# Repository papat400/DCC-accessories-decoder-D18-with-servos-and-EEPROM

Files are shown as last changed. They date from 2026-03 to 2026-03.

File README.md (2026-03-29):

# DCC-accessories-decoder-D18-with-servos-and-EEPROM
ENGLISH :
-------

Based on Ulysse's D18 decoder, allows to use servos direcly from a Nano

Quote from the Ulysse's original project (his file readme.md):

> The D18 is a DIY DCC Accessories decoder based on Arduino board.\
> At the moment, main site and documenation is in French. http://udelmas.e-monsite.com/pages/decodeur-d18.html \
> I created this github to easyly share the Arduino source code (d18_acc_decoder.ino).

Original project is available here : https://github.com/ullysse/d18

My own adaptations are:

1) Using directly some outputs of the arduino to pilot up to 16 servos (max. 12 servos) and/or digital outputs.

2) Keep a backup of the last servos Set Point and digital outputs state in EEPROM memory. This is used to retrieve positions when the arduino is turned off and on again later.
The eeprom is only adapted when a state changes. This allows at least 100,000 changes per servo or binary output, which is more than enough!

If you use and share this project, please mention Ulysse, the creator of this project.

Note : I add an Eagle zip file for the D18 PCB design (made for an arduino NANO).

### Improvements:
2025-03-02: added an output to activate the servo power relay. The sketch only activates this relay when movement is commanded, thus reducing noise.\
2026-03-29: added a feature to allow individual speed control of each servo (V3).

FRANCAIS :
--------

D'après le décodeur d'accessoires D18 d'Ulysse, cette version permet de gérer des servos directement depuis l'arduino.

Citation, d'après le fichier readme.md d'Ulysse :

> Le D18 est un décodeur d'accessoires DCC à faire soi-même avec une carte Arduino.\
> Lien vers le site principal et la documentation: http://udelmas.e-monsite.com/pages/decodeur-d18.html \
> J'ai créé ce github pour facilement partager le code source de l'Arduino (d18_acc_decoder.ino).

Le projet original est disponible ici : https://github.com/ullysse/d18

Mes adaptations sont :

1) Utiliser directement des sorties de l'arduino pour gérer jusqu'à 16 servos (max. 12 servos) et/ou sorties "tout ou rien" (binaires).

2) Effectuer un backup des position "en cours" des servos et des sorties binaires dans l'EEPROM de l'arduino. Ceci permet de récupérer les positions après coupure et réalimentation de l'arduino.
L'EEPROM n'est mise à jour que lors d'un changement d'état de la sortie. Ceci permet au moins 100000 commutations par sortie, ce qui est amplement suffisant !

Si vous utilisez et partagez ce projet, merci de mentionner le créateur initial : Ulysse.

Note : j'ai ajouté un fichier zip Eagle pour le PCB du D18 (pour un arduino NANO).

### Améliorations :
2025-03-02 : utilisation d'une sortie pour activer relais d'alimentation des servos. Le sketch ne commande ce relai que lorsqu'un mouvement est ordonné, cela évite beaucoup de bruit.\
2026-03-29 : ajout d'une fonctionnalité pour pouvoir réguler individuellement la vitesse de chaque servo (V3).

Thierry.

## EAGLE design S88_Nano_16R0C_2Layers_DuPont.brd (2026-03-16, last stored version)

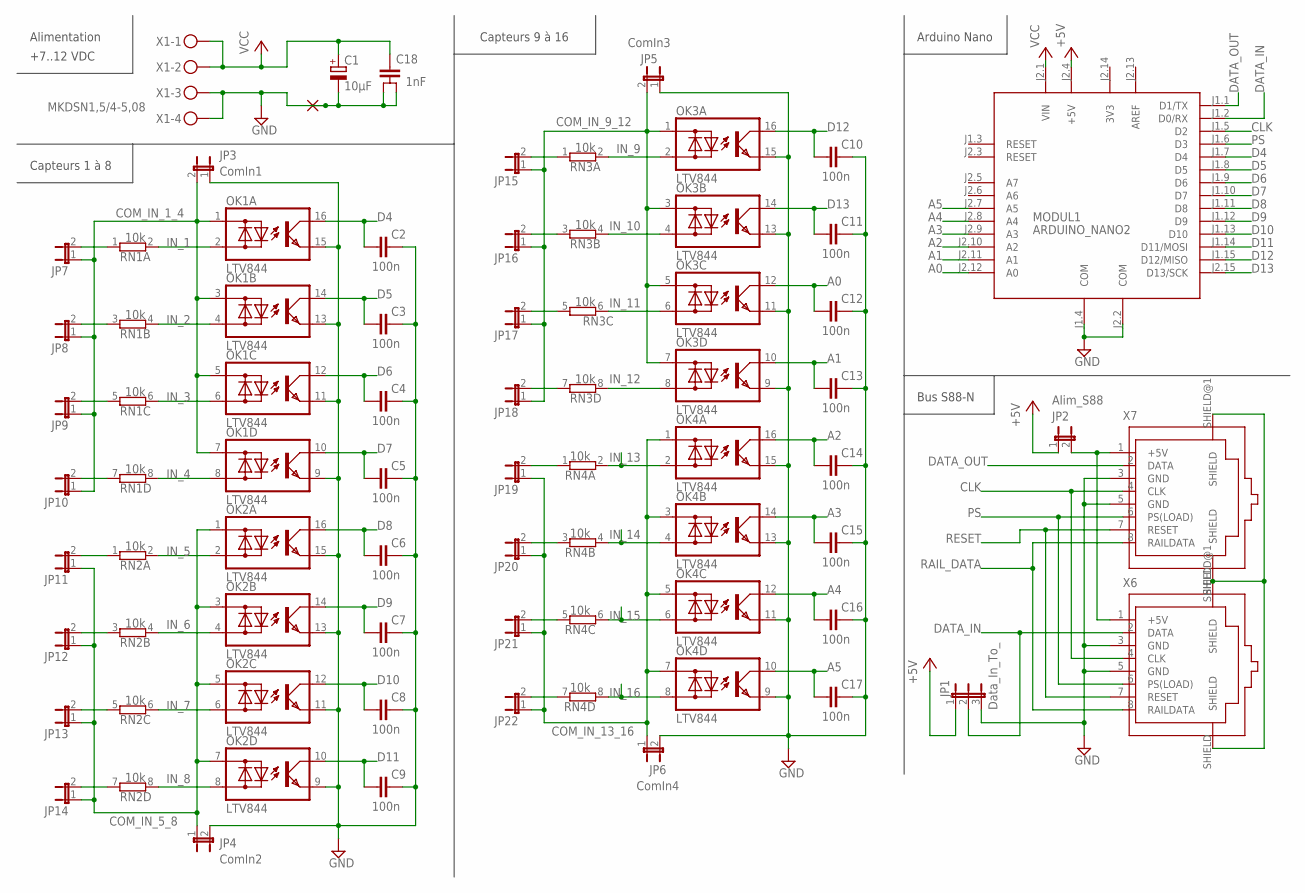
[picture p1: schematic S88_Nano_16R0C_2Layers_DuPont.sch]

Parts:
C1: 10µF; E5-6
C2, C3, C4, C5, C6, C7, C8, C9, C10, C11, C12, C13, C14, C15, C16, C17: 100n; C025-025X050
C18: 1nF; C025_050-024X070
JP1: Data_In_To_; JP2
JP2: Alim_S88; JP1
JP3: ComIn1; JP1
JP4: ComIn2; JP1
JP5: ComIn3; JP1
JP6: ComIn4; JP1
JP7, JP8, JP9, JP10, JP11, JP12, JP13, JP14, JP15, JP16, JP17, JP18, JP19, JP20, JP21, JP22: JP1E; JP1
MODUL1: ARDUINO_NANO2
OK1, OK2, OK3, OK4: LTV844; DIL16
PAD1: 1,9/0,8; 1,6/0,9
RN1, RN2, RN3, RN4: 10k; SIL8
X1: MKDSN1,5/4-5,08
X6, X7: RJ45-SHIELDED

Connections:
3V3: MODUL1.J2.14 (3V3)
+5/S88: JP2.2, X6.1 (+5V), X7.1 (+5V)
+5V: JP1.1, JP2.1, MODUL1.J2.4 (+5V)
A0: C12.1, MODUL1.J2.12 (A0), OK3.12 (C)
A1: C13.1, MODUL1.J2.11 (A1), OK3.10 (C)
A2: C14.1, MODUL1.J2.10 (A2), OK4.16 (C)
A3: C15.1, MODUL1.J2.9 (A3), OK4.14 (C)
A4: C16.1, MODUL1.J2.8 (A4), OK4.12 (C)
A5: C17.1, MODUL1.J2.7 (A5), OK4.10 (C)
AREF: MODUL1.J2.13 (AREF)
CLK: MODUL1.J1.5 (D2), X6.4 (CLK), X7.4 (CLK)
COM_IN_1_4: JP3.2, JP7.1, JP8.1, JP9.1, JP10.1, OK1.1 (AC1), OK1.3 (AC1), OK1.5 (AC1), OK1.7 (AC1)
COM_IN_5_8: JP4.1, JP11.1, JP12.1, JP13.1, JP14.1, OK2.1 (AC1), OK2.3 (AC1), OK2.5 (AC1), OK2.7 (AC1)
COM_IN_9_12: JP5.2, JP15.1, JP16.1, JP17.1, JP18.1, OK3.1 (AC1), OK3.3 (AC1), OK3.5 (AC1), OK3.7 (AC1)
COM_IN_13_16: JP6.1, JP19.1, JP20.1, JP21.1, JP22.1, OK4.1 (AC1), OK4.3 (AC1), OK4.5 (AC1), OK4.7 (AC1)
D4: C2.1, MODUL1.J1.7 (D4), OK1.16 (C)
D5: C3.1, MODUL1.J1.8 (D5), OK1.14 (C)
D6: C4.1, MODUL1.J1.9 (D6), OK1.12 (C)
D7: C5.1, MODUL1.J1.10 (D7), OK1.10 (C)
D8: C6.1, MODUL1.J1.11 (D8), OK2.16 (C)
D9: C7.1, MODUL1.J1.12 (D9), OK2.14 (C)
D10: C8.1, MODUL1.J1.13 (D10), OK2.12 (C)
D11: C9.1, MODUL1.J1.14 (D11/MOSI), OK2.10 (C)
D12: C10.1, MODUL1.J1.15 (D12/MISO), OK3.16 (C)
D13: C11.1, MODUL1.J2.15 (D13/SCK), OK3.14 (C)
DATA_IN: JP1.2, MODUL1.J1.2 (D0/RX), X6.2 (DATA)
DATA_OUT: MODUL1.J1.1 (D1/TX), X7.2 (DATA)
GND: C1.-, C2.2, C3.2, C4.2, C5.2, C6.2, C7.2, C8.2, C9.2, C10.2, C11.2, C12.2, C13.2, C14.2, C15.2, C16.2, C17.2, C18.2, C18.3, JP1.3, JP3.1, JP4.2, JP5.1, JP6.2, MODUL1.J1.4 (COM), MODUL1.J2.2 (COM), OK1.9 (E), OK1.11 (E), OK1.13 (E), OK1.15 (E), OK2.9 (E), OK2.11 (E), OK2.13 (E), OK2.15 (E), OK3.9 (E), OK3.11 (E), OK3.13 (E), OK3.15 (E), OK4.9 (E), OK4.11 (E), OK4.13 (E), OK4.15 (E), PAD1.1, X1.3, X1.4, X6.3 (GND), X6.5 (GND), X7.3 (GND), X7.5 (GND)
IN_1: OK1.2 (AC2), RN1.2
IN_2: OK1.4 (AC2), RN1.4 (2)
IN_3: OK1.6 (AC2), RN1.6 (2)
IN_4: OK1.8 (AC2), RN1.8 (2)
IN_5: OK2.2 (AC2), RN2.2
IN_6: OK2.4 (AC2), RN2.4 (2)
IN_7: OK2.6 (AC2), RN2.6 (2)
IN_8: OK2.8 (AC2), RN2.8 (2)
IN_9: OK3.2 (AC2), RN3.2
IN_10: OK3.4 (AC2), RN3.4 (2)
IN_11: OK3.6 (AC2), RN3.6 (2)
IN_12: OK3.8 (AC2), RN3.8 (2)
IN_13: OK4.2 (AC2), RN4.2
IN_14: OK4.4 (AC2), RN4.4 (2)
IN_15: OK4.6 (AC2), RN4.6 (2)
IN_16: OK4.8 (AC2), RN4.8 (2)
unnamed: JP7.2, RN1.1
unnamed: JP8.2, RN1.3 (1)
unnamed: JP9.2, RN1.5 (1)
unnamed: JP10.2, RN1.7 (1)
unnamed: JP11.2, RN2.1
unnamed: JP19.2, RN4.1
unnamed: JP14.2, RN2.7 (1)
unnamed: JP13.2, RN2.5 (1)
unnamed: JP18.2, RN3.7 (1)
unnamed: JP20.2, RN4.3 (1)
unnamed: JP12.2, RN2.3 (1)
unnamed: JP21.2, RN4.5 (1)
unnamed: JP22.2, RN4.7 (1)
unnamed: JP15.2, RN3.1
unnamed: JP16.2, RN3.3 (1)
unnamed: JP17.2, RN3.5 (1)
PS: MODUL1.J1.6 (D3), X6.6 (PS(LOAD)), X7.6 (PS(LOAD))
RAIL_DATA: X6.8 (RAILDATA), X7.8 (RAILDATA)
RESET: X6.7 (RESET), X7.7 (RESET)
SHIELD: X6.SHIELD, X6.SHIELD@1 (SHIELD), X7.SHIELD, X7.SHIELD@1 (SHIELD)
VCC: C1.+, C18.1, MODUL1.J2.1 (VIN), X1.1, X1.2

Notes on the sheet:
Alimentation
Capteurs 9 à 16
Capteurs 1 à 8
Arduino Nano
Bus S88-N
+7..12 VDC

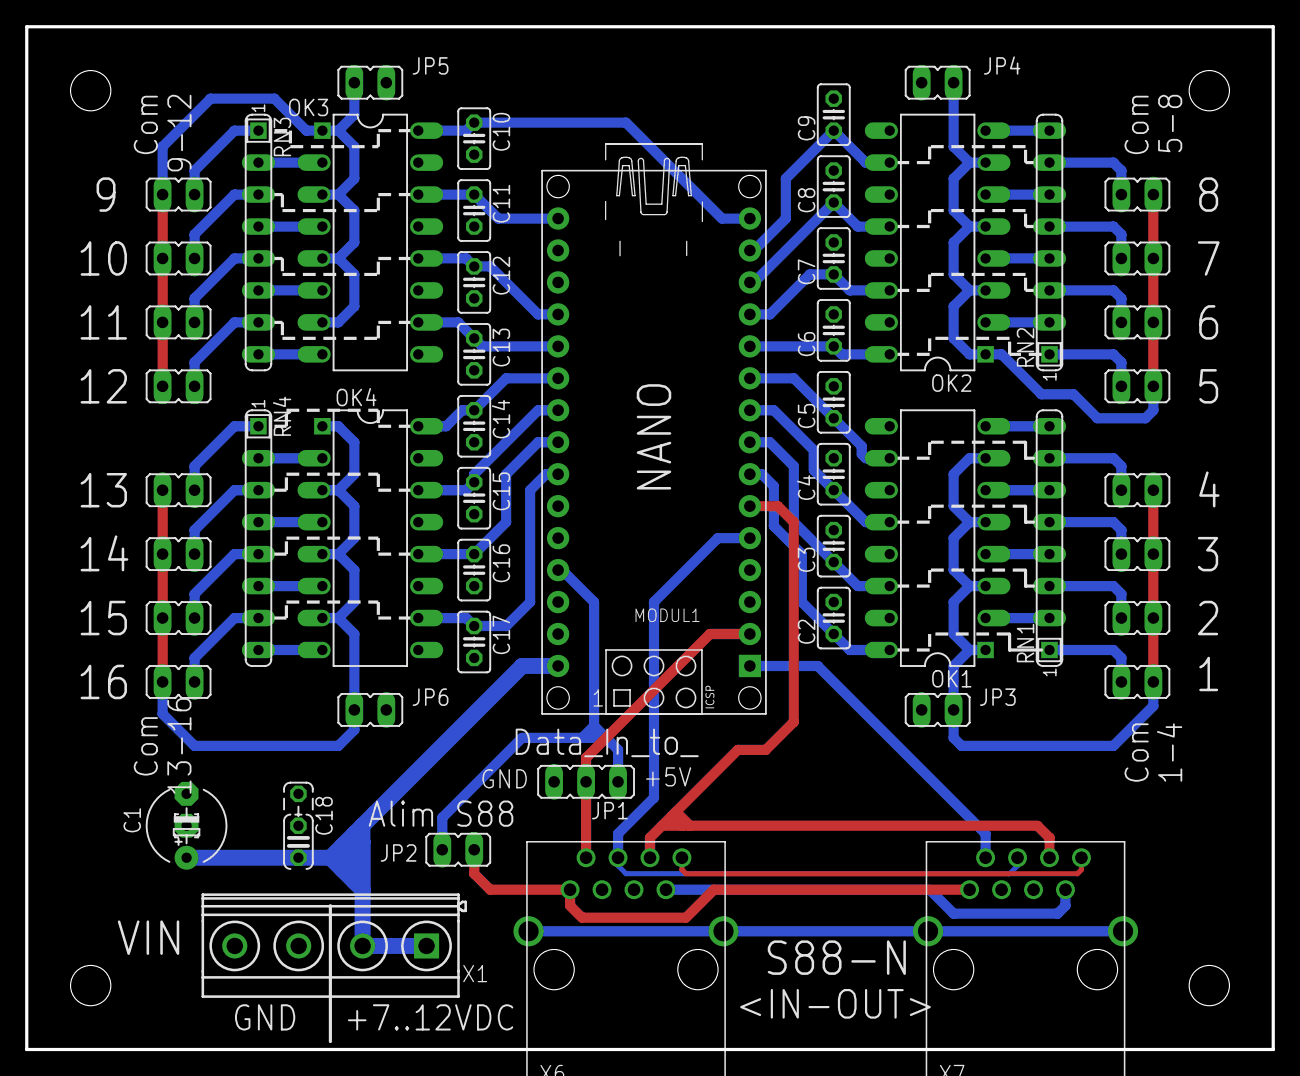
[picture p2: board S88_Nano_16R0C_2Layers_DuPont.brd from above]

Board: 2 copper layers, 99.1 x 81.3 mm, 53 parts (0 on the bottom side), 63 nets.

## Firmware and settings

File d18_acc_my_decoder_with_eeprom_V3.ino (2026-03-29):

/* D18 ACC DECODER

  Introduction:
  ENGLISH:

    Without extension, this decoder allows to control 16 direct outputs (or 8 output pairs).
        This is the double of traditional DCC accessories decoders having 4 output pairs.
        Output can be fix or generate pulses (20ms->65s with 20ms resolution).
        Configuration is done in this code (in USER part) instead of using CVs.
    You can add MAX7219/21 modules in place of 3 direct outputs. Each module can drive 64 LEDs.
        Actual SW supports 4 modules so 256 leds.
        You can also control LEDs blinking and blinking phase.
    You can add PCA9685 modules in place of 2 direct outputs. Each module adds 16 outputs.
        Each of these outputs can work in PWM mode (0-100%), this allow dimming to control for instance lights intensity or motor speed.
            To have the behavior of a traditional output, you can une 0% and 100%.
        Each of these outputs can also work in SERVO mode to control a servo-motor.
        Actual SW supports 6 modules so 96 new outputs.
    You can also drive Neopixels (chained RGB leds) in place of 1 direct out.
    To be compatible with any centrals (and mainly your central) and be versatile,
        User can map any order ("Accessory" or "Output") from DCC signal to any output.
    By default SW is delivered to manage 8 pairs on address 10 & 11

  FRANCAIS:

   Sans extension, ce décodeur permet de contrôler 16 sorties directes (ou 8 paires de sorties).
       Cela est le double d'un décodeur d'accessoires traditionnel (4 paires de sorties).
       Les sorties peuvent être fixes ou générer des impulsions (20ms->65s avec une résolution de 20ms).
   Vous pouvez ajouter des modules MAX7219/21 à la place de 3 sorties directes. Chaque module supporte 64 LEDs.
       Le programme actuel supporte 4 modules, soit 256 LEDs.
       Vous pouvez aussi contrôler le clignotement des LEDs ainsi que la phase.
   Vous pouvez ajouter des modules PCA9685 à la place de 2 sorties directes. Chaque module ajoute 16 sorties.
       Chacune de ces sorties peut fonctionner en mode PWM (0-100%), cela permet de faire varier l'éclairage ou la vitesse d'un moteur.
           Pour une sortie traditionnelle, utilisez 0% ou 100%
       Chacune de ces sorties peut fonctioner en mode SERVO (500ms->2500ms 50Hz), pour contrôler un servo-moteur.
       Le programme actuel supporte 6 modules, soit 96 nouvelles sorties.
   Vous pouvez aussi contrôler des Néopixels (LEDs chainables multicolores) à la place d'une sortie directe.
   Pour être compatible avec toutes les centrales (et surtout la vôtre) et être passe partout.
       L’utilisateur peut utiliser n'importe quel ordre DCC ("Accessory" ou "Output") pour contrôler n'importe quelle sortie.
       La configuration se fait dans ce code (dans la partie USER) au lieu d'utiliser les CV.
       Par défaut le programme est configuré pour contrôler 8 paires d sorties.

  History:
    2017-02-08: Ulysse Delmas-Begue: ajout de la rotation lente des servos
                                     changement de la resolution des tempos de 20ms a 125ms
    2017-01-12: Ulysse Delmas-Begue: support Arduino Mega board to add 50 direct outputs in addition to Arduino UNO and Nano
                                     AT Mega is enbaled when user select Arduino Mega board in Arduino IDE
                                     serigraphied number is now used for direct outputs instead of out 0-15
                                     output number is checked in user_out function
    2017-01-12: Ulysse Delmas-Begue: support 256LEDs (via 4 MAX7219/21) and 96PWM/SERCO (via 6 PCA9685)
    2017-01-11: Ulysse Delmas-Begue: add 128leds (via MAX7219/21) OK, 48pwm/servos (via PCA9685 I2C), 60neopixels  (test MAX, PCA(PWM&SRV) et pulses ok, neo not stable board finish to freeze)
    2017-01-10: Ulysse Delmas-Begue: creation (et test out ok avec D17)
    2026-03-29: Thierry:  added a feature to allow individual speed control of each servo.
                          ajout d'une fonctionnalité pour pouvoir réguler individuellement la vitesse de chaque servo.

  To be done:
    None

  License: GPL v2

  Notes:
    - I used foloowing code as startup point:
        Simple DCC Led Accessory Decoder Luca Dentella, 25.11.2017
        http://www.lucadentella.it/en/2017/11/25/dcc-decoder-accessori-per-led/
    - This code needs the following library to be installed in the Arduino IDE
        https://github.com/mrrwa/NmraDcc
    - switching on an output of the pair, automaticaaly switch off the other output
    - onboard led blinks at 1Hz or 4 Hz during 1sec when a packet matches

    Normally decoder address and pulses are set by following CVs but here they are hardcoded
    - CV513 ADR LSB 6bits
    - CV515 pair 0 pulse
    - CV516 pair 1 pulse
    - CV517 pair 2 pulse
    - CV518 pair 3 pulse duration
    - CV521 ADR MSB 3bits

  Pinout on an Arduino UNO

     CLI +++ +++ +++ +++ +++    +++ +++ +++ +++ +++ DCC  TX  RX
     D13 D12 D11 D10  D9  D8     D7  D6  D5  D4  D3  D2  D1  D0
    ###########################################################      +++ = out
    #USB###########################################TOP#view####      +-+ = out or used by MAX,PCA,NEO
    ###########################################################      use following numbers in SW: 3-12 & A0-A5
    ###########################################################      max out = 16
     x   x   x   x   x   x   x   x      A0  A1  A2  A3  A4  A5
                                   +-+ +-+ +-+ +-+ +-+ +-+
                                   CLK DAT LLED NEO SDA SCK

  Pinout on an Arduino Nano

     +++ +++ +++ +++ +++  +++ +++ +++ +++ +++ DCC          TX  RX
     D12 D11 D10  D9  D8  D7  D6  D5  D4  D3  D2 GND  RST  D1  D0    +++ = out
    ##############################################################   +-+ = out when not used by MAX,PCA,NEO
    USB ##############################################TOP#view####   use following numbers in SW: 3-12 & A0-A5
    ##############################################################   max out = 16
     D13 3.3   X  A0  A1  A2  A3  A4  A5  A6  A7  5V  RST GND VIN
     CLI          +-+ +-+ +-+ +-+ +-+ +-+
                  CLK DAT LLED NEO SDA SCK

  Pinout on Arduino Mega

  horizontal connectors

     CLI +++ +++ +++ +++ +++    +++ +++ +++ +++ +++ DCC  TX  RX    +++ +++ +++ +++ +++ +++ +++ +++
     D13 D12 D11 D10  D9  D8     D7  D6  D5  D4  D3  D2  D1  D0    D14 D15 D16 D17 D18 D19 D20 D21
    #######################################################################################################
    USB############################################TOP#view################################################
    #######################################################################################################
    #######################################################################################################
     x   x   x   x   x   x   x   x      A0  A1  A2  A3  A4  A5  A6 A7     A8  A9 A10 A11 A12 A13 A14 A15
                                       +-+ +-+ +-+ +-+ +-+ +-+ +++ +++   +++ +++ +++ +++ +++ +++ +++ +++
                                       CLK DAT LLED NEO SDA SCK

  vertical connector:

         GND ##### GND
     +++ D22 ##### D23 +++      +++ = out
     +++ D24 ##### D25 +++      out when not used by MAX,PCA,NEO
     +++ D26 ##### D27 +++      use following numbers in SW: 3-12,14-53 & A0-A15
     +++ D28 ##### D29 +++      max out = 66
     +++ D30 ##### D31 +++
     +++ D32 ##### D33 +++
     +++ D34 ##### D35 +++
     +++ D36 ##### D37 +++
     +++ D38 ##### D39 +++
     +++ D40 ##### D41 +++
     +++ D42 ##### D43 +++
     +++ D44 ##### D45 +++
     +++ D46 ##### D47 +++
     +++ D48 ##### D49 +++
     +++ D50 ##### D51 +++
     +++ D52 ##### D53 +++
         GND ##### GND
*/
//==============================================================================================
/*

  English :
  ---------
  Adaptations made to use servos directly on arduino pins.
  Author : Thierry.

  The main changes are made in 5 "blocks" of code, named : part 1, 2, 3, 4 and 5.
  part 1 is in "declaration" section;
  part 2 in the user_init() function;
  part 3 in the user_notify_bas_acc_dec();
  part 4 containing the functions created for this modification;
  part 5 in the loop().

  Some additional lines are spotted by the comment !-Thierry-!
  ++++++++++++++++++++++++++++++++++++++++++++++++++++++++++++++++++++++++++++++++++

  Notes about DCC decoding related to the intended use :
  ------------------------------------------------------

  Used command station : Yaassan's Desktop Station (hereinafter named DS) - for details, see https://desktopstation.net/
  DS sends accessory orders in DCC and / or MM2 (configurable choice).
  D18 decoder don't manage MM2, all that follows only relates to the decoding of DCC accessories.

  Used DCC mode by DS : "Basic Accessory Decoder"
  DS can manage 2044 accessories addresses, ie 4 accessories for each of the 511 basic DCC addresses.

  About turnouts:

  One DS address "uses" two consecutive bits in one DCC address.
    Example:
      DS address  -   DS functionality (examples)   -   DCC address
      ----------      ---------------------------       -----------
           1       -  turnout in deviated position  -  1 / bit 0 (pulse)
           1       -  turnout in right position     -  1 / bit 1 (pulse)
           2       -  two-color signal RED          -  1 / bit 2
           2       -  two-color signal GREEN        -  1 / bit 3
           3       -  turnout in deviated position  -  1 / bit 4 (pulse)
           3       -  turnout in right position     -  1 / bit 5 (pulse)
           4       -  two-color signal RED          -  1 / bit 5
           4       -  two-color signal GREEN        -  1 / bit 7

    For each of its turnout's addresses, DS sends a pulse to the "ONE" state for a few tenths of seconds and then resets the output to "ZERO".
      This indicates that the "standard" of DS operation clearly relates to the use of solenoid-controlled turnouts.
    Each command is repeated four times.
      Example:
      Turnout command on address DS 1: switching on "straight"
        #3 129 249 120 BAS ACC pkt adr(1-511)=1 out(0-7)=1 val(0-1)=1 => command DCC address n°1 / bit 1 to the state ONE ; repeated four times
        #3 129 249 120 BAS ACC pkt adr(1-511)=1 out(0-7)=1 val(0-1)=1
        #3 129 249 120 BAS ACC pkt adr(1-511)=1 out(0-7)=1 val(0-1)=1
        #3 129 249 120 BAS ACC pkt adr(1-511)=1 out(0-7)=1 val(0-1)=1
        ... a few tenths of a second ...
        #3 129 241 112 BAS ACC pkt adr(1-511)=1 out(0-7)=1 val(0-1)=0 => command DCC address n°1 / bit 1 to the state ZERO ; repeated four times
        #3 129 241 112 BAS ACC pkt adr(1-511)=1 out(0-7)=1 val(0-1)=0
        #3 129 241 112 BAS ACC pkt adr(1-511)=1 out(0-7)=1 val(0-1)=0
        #3 129 241 112 BAS ACC pkt adr(1-511)=1 out(0-7)=1 val(0-1)=0

      Switching on "deviated turnout" will use the same scheme on DCC address 1 / bit 0

    Improvement :
    -------------
      Added an option to use a servo power relay.

      Cause: on power-ON, there is still no PWM signal to the servos. If they are already supplied with + 5V, they will then quickly move 
        to a random position and certainly exceed the programmed stops, which could be bad for the driven mechanics.
      Solution: add a relay to supply power to the servos only when the PWM signal is present.
      Disadvantage: this uses one of the available outputs.


  Français :
  ----------
  Adaptations apportées pour gérer des servos directement depuis les pins Arduino
  Auteur : Thierry.

  Modifications principales effectuées en 5 "blocs" de code, nommés : partie 1, 2, 3, 4 et 5.
  partie 1 dans les déclarations ;
  partie 2 dans la fonction user_init() ;
  partie 3 dans la fonction user_notify_bas_acc_dec() ;
  partie 4 contenant les fonctions créées pour cette modification, ;
  partie 5 dans la fonction loop()
  
  Quelques lignes supplémentaires sont repérables par le commentaire !-Thierry-! .
  ++++++++++++++++++++++++++++++++++++++++++++++++++++++++++++++++++++++++++++++++

  Notes sur le décodage DCC lié à l'utilisation envisagée :
  ---------------------------------------------------------
  Station de commande utilisée : Desktop Station (ci-après nommé DS) de Yaasan - voir https://desktopstation.net/
  DS gère les commandes d'accessoires en DCC et / ou en MM2 (choix paramétrable).
  Le MM2 n'est pas traité par le décodeur D18, tout ce qui suit ne concerne que le décodage d'accessoires DCC.

  Mode utilisé par DS en DCC : "Basic Accessory Decoder"
  DS peut piloter 2044 adresses d'accessoires, càd 4 accessoires pour chacune des 511 adresses basiques DCC.

  Concernant les aiguilles :

    Une adresse DS "consomme" deux bits consécutifs dans l'adresse DCC.
      Exemple :
      adresse DS   -      fonctionnalité DS         -   adresse DCC
      ----------          -----------------             -----------
           1       -  aiguille en position déviée   -  1 / bit 0 (impulsion)
           1       -  aiguille en position droite   -  1 / bit 1 (impulsion)
           2       -  signal bicolore ROUGE         -  1 / bit 2
           2       -  signal bicolore VERT          -  1 / bit 3
           3       -  aiguille en position déviée   -  1 / bit 4 (impulsion)
           3       -  aiguille en position droite   -  1 / bit 5 (impulsion)
           4       -  signal bicolore ROUGE         -  1 / bit 5
           4       -  signal bicolore VERT          -  1 / bit 7

    Pour chacune de ses adresses concernant une aiguille, DS envoie une impulsion à l'état UN durant quelques dixièmes de secondes puis remet la sortie a l'état ZERO.
      Ceci indique que la "norme" de fonctionnement DS concerne clairement l'utilisation d'aiguilles à commande par solénoides.
    Chaque commande est répétée quatre fois.
      Exemple:
      Commande de l'aiguille sur adresse DS 1 : commutation sur "aiguille droite"
        #3 129 249 120 BAS ACC pkt adr(1-511)=1 out(0-7)=1 val(0-1)=1 => commande adresse DCC n°1 / bit 1 à l'état UN ; répétée quatre fois
        #3 129 249 120 BAS ACC pkt adr(1-511)=1 out(0-7)=1 val(0-1)=1
        #3 129 249 120 BAS ACC pkt adr(1-511)=1 out(0-7)=1 val(0-1)=1
        #3 129 249 120 BAS ACC pkt adr(1-511)=1 out(0-7)=1 val(0-1)=1
        ... délai de quelques dixièmes de seconde ...
        #3 129 241 112 BAS ACC pkt adr(1-511)=1 out(0-7)=1 val(0-1)=0 => commande adresse DCC n°1 / bit 1 à l'état ZERO ; répétée quatre fois
        #3 129 241 112 BAS ACC pkt adr(1-511)=1 out(0-7)=1 val(0-1)=0
        #3 129 241 112 BAS ACC pkt adr(1-511)=1 out(0-7)=1 val(0-1)=0
        #3 129 241 112 BAS ACC pkt adr(1-511)=1 out(0-7)=1 val(0-1)=0

      La commutation sur "aiguille déviée" utilisera le même schéma sur l'adresse DCC 1 / bit 0

    Améliorations :
    --------------
    Ajouté une option utilisant un relais de puissance pour les servos.

    Cause : à la mise sous tension, il n'y a pas encore de signal PWM vers les servos. Si ils sont déjà alimentés en puissance, ils vont alors se positionner rapidement 
      sur une position aléatoire et certainement dépasser les butées programmées, cela pouvant être mauvais pour la mécanique entraînée.
    Remède : ajout d'un relais pour n'alimenter les servos en puissance que lorsque le signal PWM est présent.
    Inconvénient : cela utilise une des sorties disponibles.

*/

//==============================================================================================
//     USER PART
//==============================================================================================

// functions available for user
void user_out(byte num, byte val);
void user_led(byte num, byte val);
void user_led_cli(byte num, byte val);
void user_led_pha(byte num, byte val);
void user_neo(byte num, byte r, byte v, byte b);
void user_pwm_0_100(byte num, byte val);
void user_servo_500_2500(byte num, unsigned int val);
void user_servo_speed(byte num, byte speed);   //delta pulse us / 125ms
void user_tempo_start(byte num_tempo, unsigned int duration_ms);
void user_blink(void);

/* !-Thierry-! */
void user_servosOnBoard(void); // function created for managing servos on the Arduino board outputs / fonction créée pour la gestion des servos sur les sorties de la carte arduino.
void user_servoOut(byte nServo, boolean val);
void user_outTwin_0_1(byte out_0, byte out_1); // managing a pair of outputs for switch actuation / gestion d'un couple de sorties pour actionnement aiguillage.
/* --Thierry-- */

// PIN assignation
#define USER_USE_MAX  0   // 1 to use MAX7219/21 (out A0, A1 & A2 no more available)
#define USER_USE_PCA  0   // 1 to use PCA9685 (out A3 & A4 no more available)
#define USER_USE_NEO  0   // 1 to use neopixels (out A5 no more available)

// User defines 
/*  Define below the DCC addresses you need (look at the examples)
    Définissez ci-dessous les adresses DCC dont vous avez besoin (regardez les exemples). */
//#define DECODER_ADR_1 1  // Adresses DS 1..4 ; DCC 1
//#define DECODER_ADR_8 8  // Adresses DS 29..32 ; DCC 8
//#define DECODER_ADR_x x // with x = DCC decoder address.
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
void loop(void)
{
  unsigned long m = millis();
  unsigned long time1;


  fast_loop();

  /*+++++++++++++++++++++++++++++++++++++++++++++++++++++++++++++++++++++++++++++++++++
    +++++++++++++++++++++++++++++++++++++++++++++++++++++++++++++++++++++++++++++++++++

    Modifications, part 5 :
    -----------------------
      */
      #if USER_USE_SERVOS_ON_BOARD == 1
        user_servosOnBoard();
      #endif

      fast_loop();

        /* Relay activation time management :
            1) On start-up, wait for the sketch to loop 5 times before releasing the relay; 
            This ensures that the servo outputs are active at the correct control frequency.
            The activation time is limited to a few seconds.
            2) The relay is activated if a movement is requested, the activation time being limited to a few seconds after the movement.
            limited to a few seconds after the movement.

          Gestion de la durée d'activation du relais :
            1) Au démarrage, on attend que le sketch ait bouclé 5 fois avant de libérer le relais ; 
            ceci afin que les sorties servo soient actives à la fréquence de pilotage correcte.
            La durée d'activation est limitée à quelques secondes.
            2) On active le relais si un mouvement est demandé, la durée d'activation étant
            limitée à quelques secondes après le mouvement. */

        if (USER_USE_POWER_RELAY == 1) {    
          if (waitBefore5V > 0) --waitBefore5V;
          if (waitBefore5V == 0) {
            relayOn = 1;
            waitBefore5V--;
          }
          
          if (relayOn) {
            timerRelay = millis() + RELAY_ACTIV_TIME;
            relayOn = 0;
          }

          if (millis() < timerRelay) {
            digitalWrite(pinOut[USER_POWER_RELAY_OUTPUT],HIGH);  // activates the relay via the selected output / active le relais via la sortie sélectionnée.
          }
          else {
            digitalWrite(pinOut[USER_POWER_RELAY_OUTPUT],LOW);  // disables the relay / désactive le relais
          }
          
          fast_loop();
        }
 
  /*  Modifications : end of part 5
      +++++++++++++++++++++++++++++++++++++++++++++++++++++++++++++++++++++++++++++++++++
      +++++++++++++++++++++++++++++++++++++++++++++++++++++++++++++++++++++++++++++++++++
  */

  // attente 125ms
  time1 = millis();
  if ((time1 - time0) < 125) return;

  // on arrive ici toute les 125ms
  //Serial.println(time1 - time0);
  time0 = time1;
  cpt_125ms++;

  // gestion des tempos
  tempo_maj();

  // tache de fond de l'utilisateur
  user_125ms();

  // clignotement de la LED a 1Hz  (ou 4Hz pendant 2s lorsque l'on recoit un packet)
  if (rx == 0) { if (cpt_125ms & 4) digitalWrite(PIN_LED, HIGH); else digitalWrite(PIN_LED, LOW); }
  else         { if (cpt_125ms & 1) digitalWrite(PIN_LED, HIGH); else digitalWrite(PIN_LED, LOW); }

  // mise a jour des LEDs
#if USER_USE_MAX == 1
  led_cpt++; if (led_cpt == 8) led_cpt = 0; // 0 - 7 used to blink leds (off 0-3, on 4-7)
  led_maj(0); fast_loop(); // total led_maj lasts 5ms, so we cut it to call process_packet() between;
  led_maj(1); fast_loop();
#endif

  // mise a jour des sorties PWM et servos
#if USER_USE_PCA == 1
  pca9685_slow_srv(); // compute positions for servos using slow movements
  index = 0;
  while (1) // total pca9685_maj lasts between 0 and 60ms, so we cut it to call process_packet() between
  {
    if (pca9685_maj(index)) break; //return 1 when nothing else to update
    fast_loop();
    index++;
  }
#endif

  // demande de mise a jour des neopixels
#if USER_USE_NEO == 1
  neo_maj();
#endif
}

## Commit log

2026-03-16 Update README with new version details
    Added an edit note regarding the replacement of input terminal blocks with DuPont connectors.
2026-03-29 Update README with versioning for servo speed control
